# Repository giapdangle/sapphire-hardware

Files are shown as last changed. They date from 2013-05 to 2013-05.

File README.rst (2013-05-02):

Sapphire Hardware
=================

This repository contains the hardware designs for the Sapphire wireless platform.

License Information
-------------------

The contents of this repository are released under the Creative Commons Attribution-ShareAlike 3.0 Unported license.

See http://creativecommons.org/licenses/by-sa/3.0/ for more information.

Commercial Usage
----------------

While the license grants rights for commercial usage of the hardware designs, the Sapphire name, logo, and branding are NOT included in these rights.  If you intend to sell a derivative version of the hardware designs contained herein, you MUST remove the Sapphire name, logo, and any other markings that could confuse your product with one produced by Sapphire Open Systems.

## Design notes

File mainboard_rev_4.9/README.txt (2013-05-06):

Blue Sapphire
Schematic notes

CP2104 USB power:
The CP2104 is powered by VUSB, 5 volts direct from the USB connector (J2). VUSB flows through D1 to energize V_IN and the main regulator, unless a supply of higher voltage is applied to the DC input (J1). VUSB is fused at 500 mA in case a short circuit is connected to the DC input. The CP2104 itself is powered from VUSB and it's internal 3.4 volt regulator. 

The IO supply is directly connected to the CP2104 internal 3.4 volt supply. This is within the tolerance range of the 3.3 volt IO on the AVR microcontroller, however, it does mean that this board cannot be used with a main regulator (U2) at less than 3.3 volts. The advantage to this configuration is that the CP2104 is only (and entirely) powered by VUSB.  If there is no USB connection, the CP2104 will draw no current whatsoever. If the CP2104 VIO pin is connected to the main 3.3 volt board supply, it will leak several hundred microamps, even with the rest of the CP2104 unpowered.

CP2104 notes:
The EEPROM config for Vendor ID, S/N, etc can only be programmed once. This is a stark contrast to the FTDI parts. Note that C14 is required for EEPROM programming.

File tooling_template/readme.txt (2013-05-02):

Board name
Date

Board size:
X x Y in

Soldermask: Blue
Silkscreen: White
Plating: Silver

Gerbers:
main_c01.gbr	Top copper
main_c02.gbr	Bottom copper
main_sm1.gbr	Top solder mask
main_sm2.gbr	Bottom solder mask
main_sp1.gbr	Top solder paste
main_ss1.gbr	Top silk screen
main_ss2.gbr	Bottom silk screen

NC Drill:
main.drd

Do not populate:
x,x,x

Notes:

Contact:

Name
Company Name

E-mail

Phone

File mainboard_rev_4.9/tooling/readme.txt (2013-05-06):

Board name
Blue Sapphire 4.9

Board size:
1.45 x 2.61 in

Soldermask: Blue
Silkscreen: White
Plating: HASL

Gerbers:
main_c01.gbr	Top copper
main_c02.gbr	Bottom copper
main_sm1.gbr	Top solder mask
main_sm2.gbr	Bottom solder mask
main_sp1.gbr	Top solder paste
main_ss1.gbr	Top silk screen
main_ss2.gbr	Bottom silk screen

NC Drill:
main.drd

Do not populate:
R5

Contact:

Jeremy Billheimer
Sapphire Open Systems, LLC

jeremy@sapphireos.com

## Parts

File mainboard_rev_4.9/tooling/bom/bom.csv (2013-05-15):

Line item | Digikey PN | Description | Qty per unit | Ref Des | Notes
1 | 311-10KGRCT-ND | Res, 10K, 0603 | 2 | R3, R4
2 | 311-100KGRCT-ND | Res, 100K, 0603 | 1 | R2
3 | 311-150GRCT-ND | Res, 150, 0603 | 3 | R6, R7, R8
4 | 490-3895-1-ND | Cap, 1u, 0603 | 11 | C2, C3, C5, C6, C8, C10, C11, C12, C13, C15, C17
5 | 445-6797-1-ND | Cap, 22u, 0805 | 1 | C1
6 | 311-1371-1-ND | Cap, 4.7u 0805 | 1 | C14
7 | 445-5046-1-ND | Cap, 9p, 0603 | 4 | C7, C9, C18, C19
8 | 712-1332-1-ND | Cap, RF, 22p, 0603 | 1 | C16
9 | CG0603MLC-05ECT-ND | ESD, 0603 | 3 | D6, D7, D8
10 | 507-1519-1-ND | Fuse, 0805 | 1 | F1
11 | SER3628CT-ND | Crystal, 16MHz, SMT | 1 | Y1
12 | 887-1505-1-ND | Crystal, 32KHz, SMT | 1 | Y2
13 | BAS40-04-FDICT-ND | Diode, dual series, SOT23 | 2 | D1, D2
14 | 475-1410-1-ND | LED, green, 0805 | 1 | D3
15 | 754-1135-1-ND | LED, yellow, 0805 | 1 | D4
16 | 475-1415-1-ND | LED, red, 0805 | 1 | D5
17 | ATMEGA128RFA1-ZU-ND | IC, ATMega128RFA1, QFN64 | 1 | U3
18 | SST25VF080B-80-4I-S2AE-ND | IC, SPI Flash, 8 MBit, SOIC8 | 1 | U6
19 | 712-1538-1-ND | IC, Balun, 2450 MHz, DFN6 | 1 | U5
20 | MCP1703T-3302E/CBCT-ND | IC, LDO Reg, 3.3v, SOT23 | 1 | U2
21 | 336-2008-5-ND | IC, CP2104 USB, QFN24 | 1 | U4
22 | MCP121T-195I/LBCT-ND | IC, MCP121 Reset supervisor, SOT23 | 1 | U1
23 | CP-102A-ND | Conn, DC Power, PTH | 1 | J1
24 | H11671CT-ND | Conn, Mini USB, SMT | 1 | J2 | H11671TR-ND for 1500+, tape and reel
25 | S7014-ND | Conn, Female header, 1x16, PTH | 2 | J3, J4
26 | 450-1757-1-ND | Switch, tactile, SMT, SPST-NO | 1 | S1 | 450-1757-2-ND for 1200+, tape and reel
27 | 311-1.0MGRCT-ND | Res, 1M, 0603 | 1 | R1

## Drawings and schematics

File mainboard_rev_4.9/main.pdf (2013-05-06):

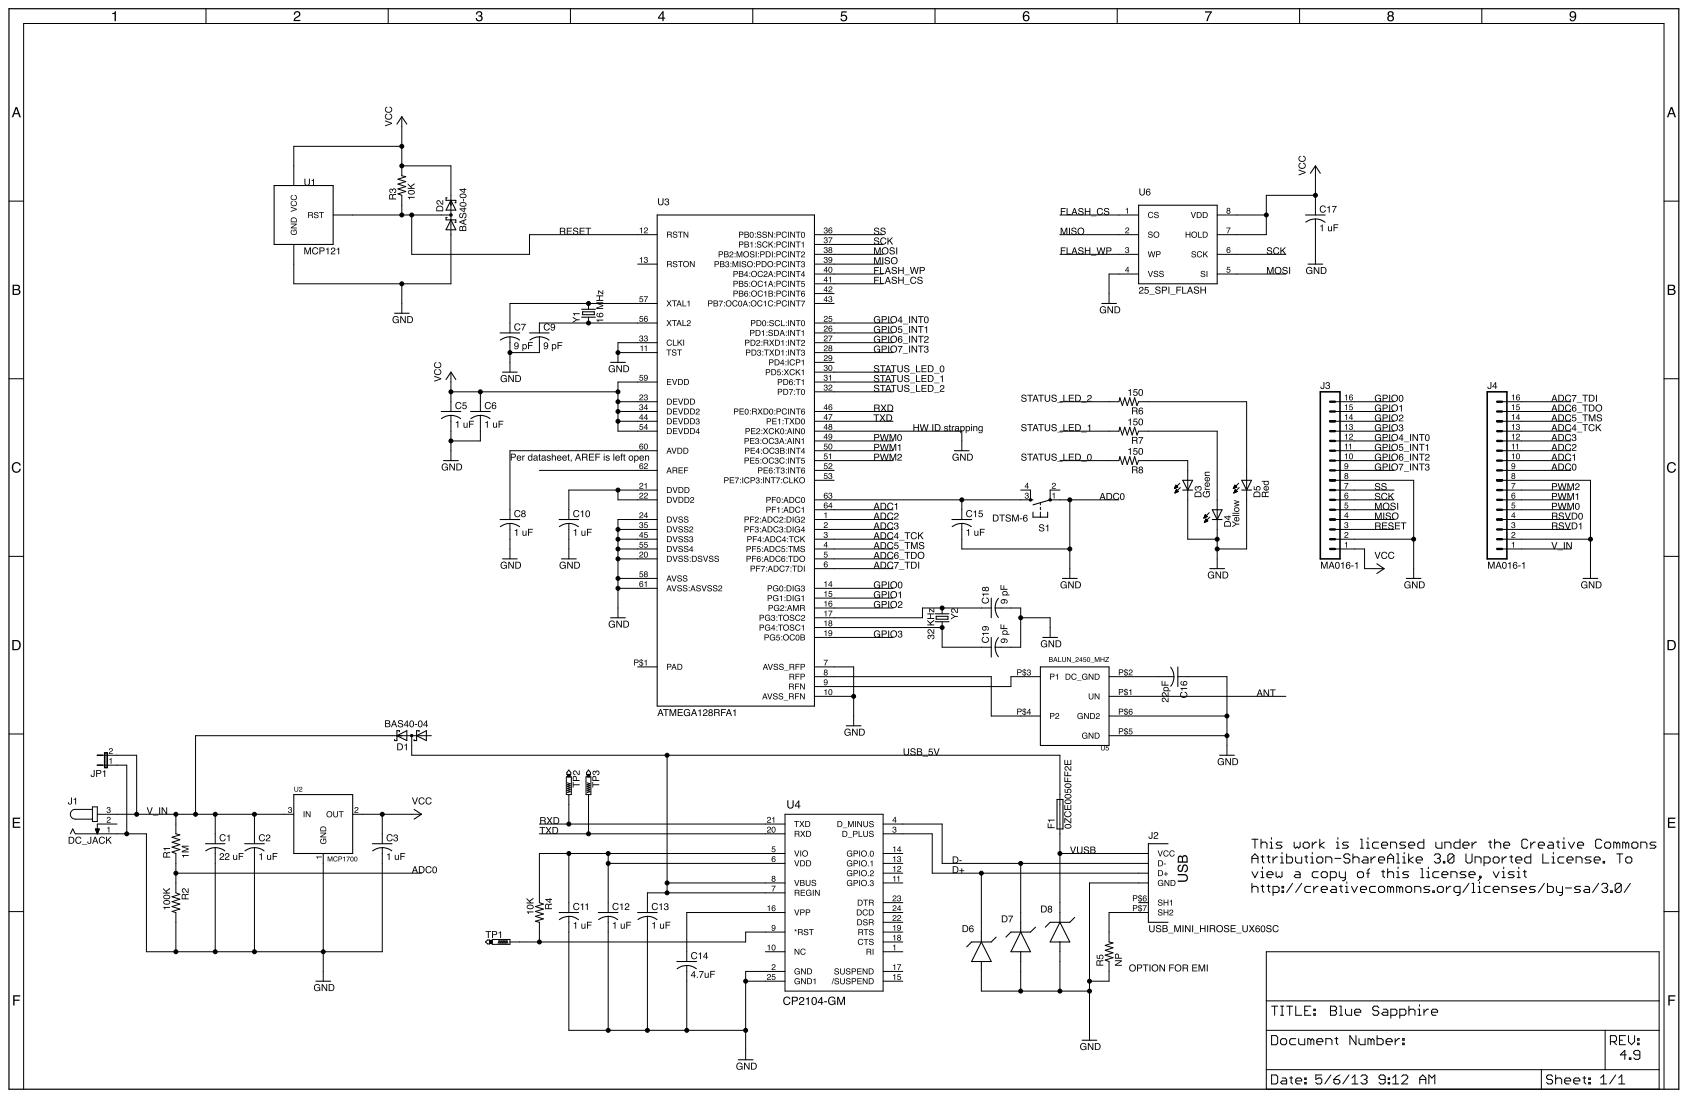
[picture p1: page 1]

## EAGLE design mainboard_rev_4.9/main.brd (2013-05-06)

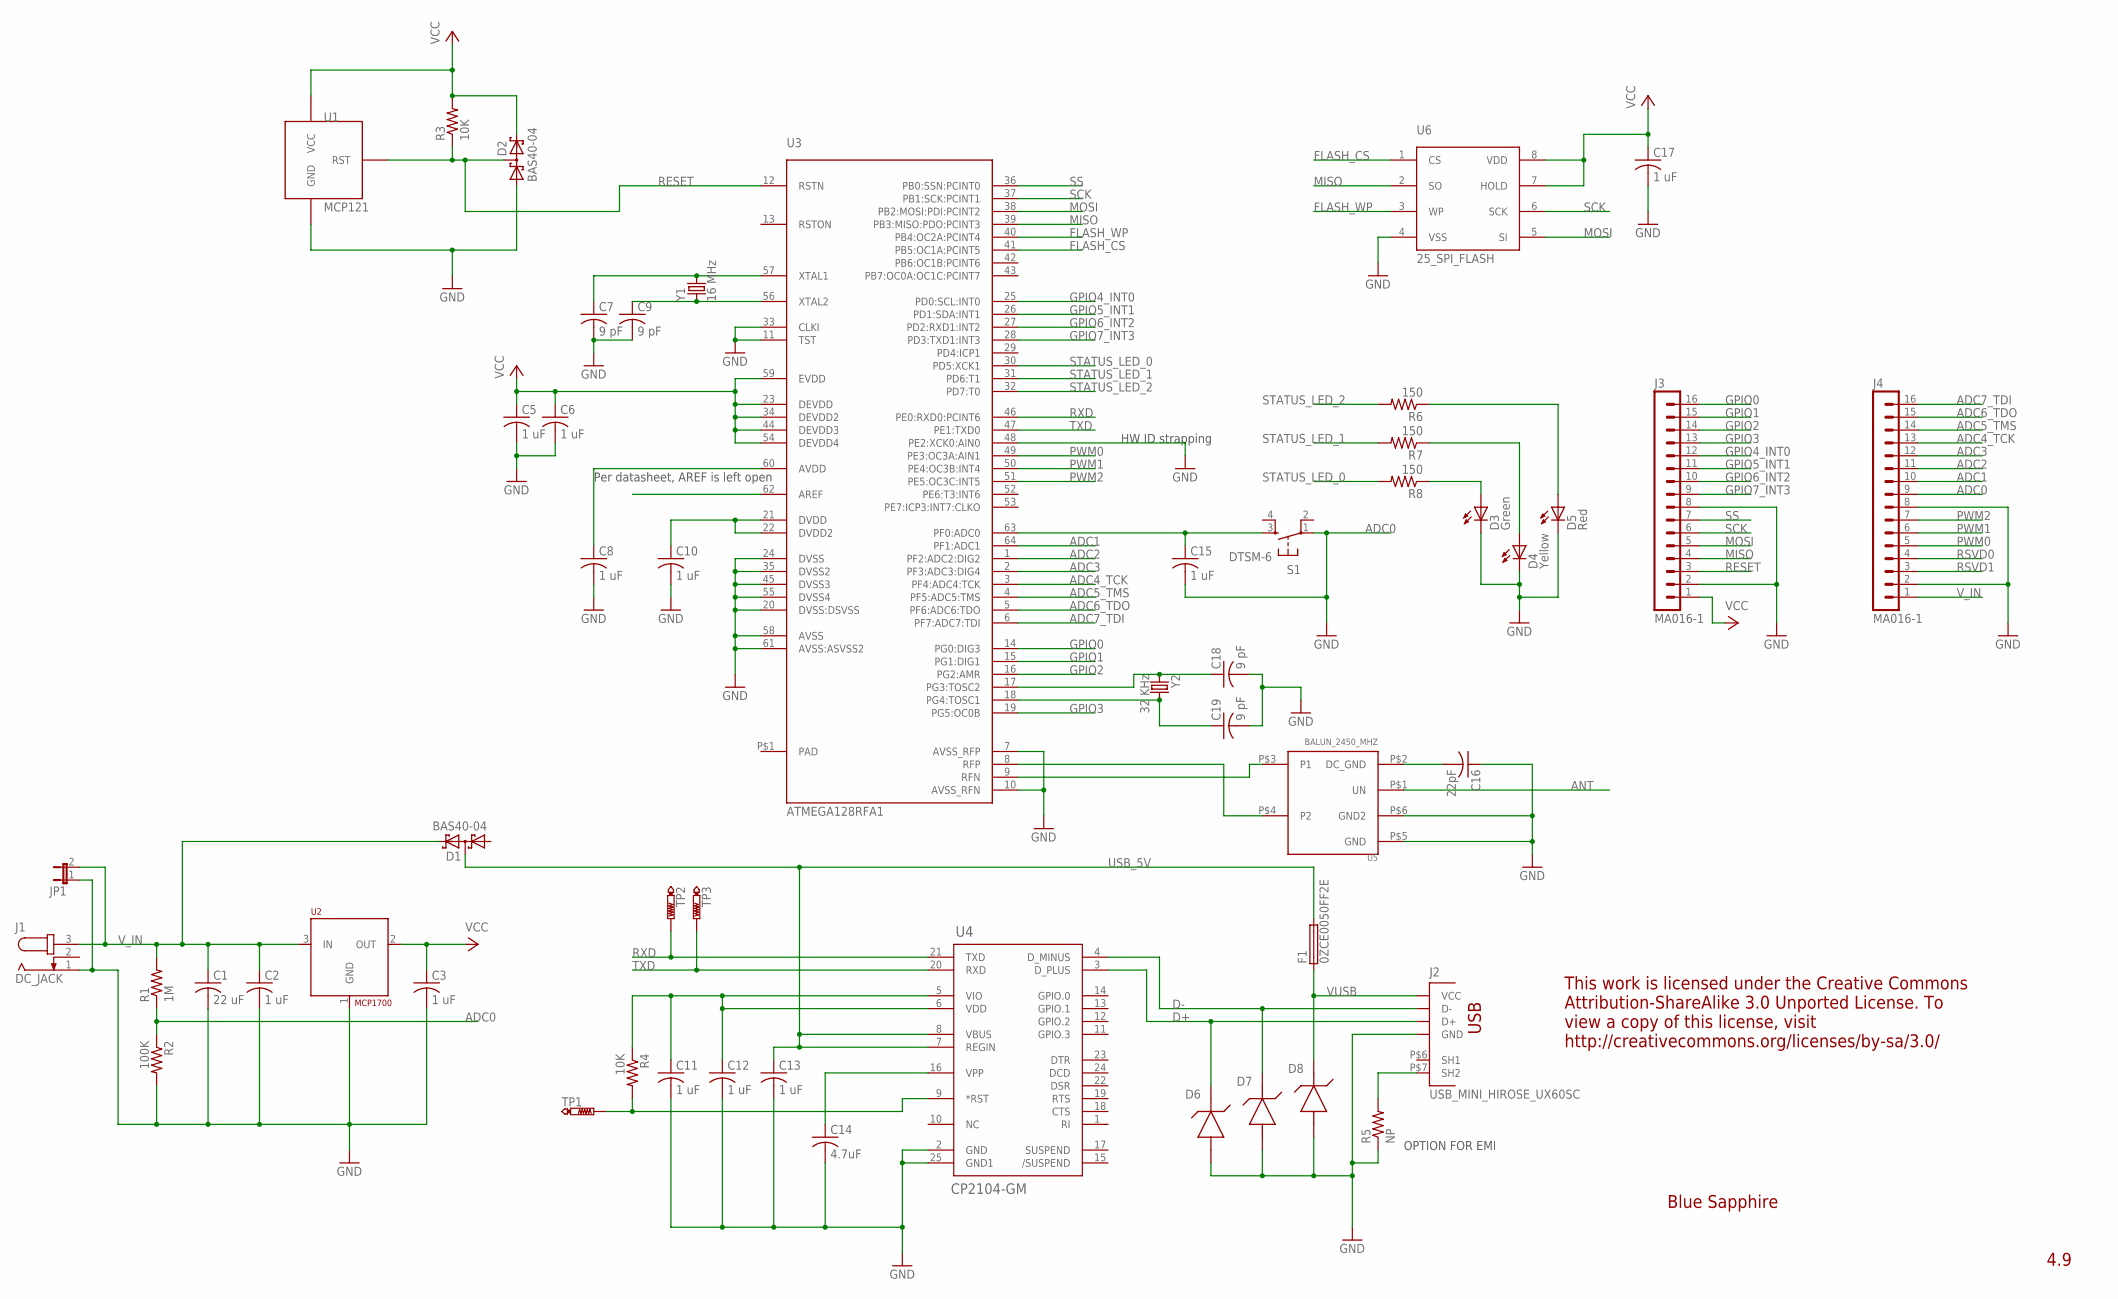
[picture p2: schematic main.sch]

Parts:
C1: 22 uF; C0805K
C2, C3, C5, C6, C8, C10, C11, C12, C13, C15, C17: 1 uF; C0603K
C7, C9, C18, C19: 9 pF; C0603K
C14: 4.7uF; C0805K
C16: 22pF; C0603K
D1, D2: BAS40-04; SOT23
D3: Green; CHIPLED_0805
D4: Yellow; CHIPLED_0805
D5: Red; CHIPLED_0805
D6, D7, D8: CG0603MLC; C0603
F1: 0ZCE0050FF2E; C0805
J1: DC_JACK; CONN_DC_JACK
J2: USB_MINI_HIROSE_UX60SC; USB-MINI-B_HIROSE_UX60SC
J3, J4: MA016-1
JP1: JP1E; JP1
R1: 1M; R0603
R2: 100K; R0603
R3, R4: 10K; R0603
R5: NP; R0603
R6, R7, R8: 150; R0603
S1: DTSM-6
TP1, TP2, TP3: PTR1B1,27; B1,27
U1: MCP121; SOT23
U2: MCP1700; SOT23
U3: ATMEGA128RFA1; MLF64
U4: CP2104-GM; QFN24_4X4
U5: BALUN_2450_MHZ; BALUN_0805
U6: 25_SPI_FLASH; SO-8WIDE
Y1: 16 MHz; XTAL_3.2X2.5
Y2: 32 KHz; XTAL_3.2X1.5

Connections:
ADC0: C15.1, J4.9, R1.1, R2.1, S1.3, U3.63 (PF0:ADC0)
ADC1: J4.10, U3.64 (PF1:ADC1)
ADC2: J4.11, U3.1 (PF2:ADC2:DIG2)
ADC3: J4.12, U3.2 (PF3:ADC3:DIG4)
ADC4_TCK: J4.13, U3.3 (PF4:ADC4:TCK)
ADC5_TMS: J4.14, U3.4 (PF5:ADC5:TMS)
ADC6_TDO: J4.15, U3.5 (PF6:ADC6:TDO)
ADC7_TDI: J4.16, U3.6 (PF7:ADC7:TDI)
ANT: U5.P$1 (UN)
AREF: U3.62 (AREF)
AVDD: C8.1, U3.60 (AVDD)
D+: D6.2 (LINE), J2.P$3 (D+), U4.3 (D_PLUS)
D-: D7.2 (LINE), J2.P$2 (D-), U4.4 (D_MINUS)
DVDD: C10.1, U3.21 (DVDD), U3.22 (DVDD2)
FLASH_CS: U3.41 (PB5:OC1A:PCINT5), U6.1 (CS)
FLASH_WP: U3.40 (PB4:OC2A:PCINT4), U6.3 (WP)
GND: C1.2, C2.2, C3.2, C5.2, C6.2, C7.2, C8.2, C9.2, C10.2, C11.2, C12.2, C13.2, C14.2, C15.2, C16.1, C17.2, C18.2, C19.2, D2.1 (A1), D3.C, D4.C, D5.C, D6.1 (GND), D7.1 (GND), D8.1 (GND), J1.1, J2.P$5 (GND), J3.2, J3.8, J4.2, J4.8, JP1.1, R2.2, R5.1, S1.1, U1.3 (GND), U2.1 (GND), U3.7 (AVSS_RFP), U3.10 (AVSS_RFN), U3.11 (TST), U3.20 (DVSS:DSVSS), U3.24 (DVSS), U3.33 (CLKI), U3.35 (DVSS2), U3.45 (DVSS3), U3.48 (PE2:XCK0:AIN0), U3.55 (DVSS4), U3.58 (AVSS), U3.61 (AVSS:ASVSS2), U4.2 (GND), U4.25 (GND1), U5.P$5 (GND), U5.P$6 (GND2), U6.4 (VSS)
GPIO0: J3.16, U3.14 (PG0:DIG3)
GPIO1: J3.15, U3.15 (PG1:DIG1)
GPIO2: J3.14, U3.16 (PG2:AMR)
GPIO3: J3.13, U3.19 (PG5:OC0B)
GPIO4_INT0: J3.12, U3.25 (PD0:SCL:INT0)
GPIO5_INT1: J3.11, U3.26 (PD1:SDA:INT1)
GPIO6_INT2: J3.10, U3.27 (PD2:RXD1:INT2)
GPIO7_INT3: J3.9, U3.28 (PD3:TXD1:INT3)
MISO: J3.4, U3.39 (PB3:MISO:PDO:PCINT3), U6.2 (SO)
MOSI: J3.5, U3.38 (PB2:MOSI:PDI:PCINT2), U6.5 (SI)
unnamed: C16.2, U5.P$2 (DC_GND)
unnamed: C19.1, U3.18 (PG4:TOSC1), Y2.P$2 (2)
unnamed: U3.8 (RFP), U5.P$4 (P2)
unnamed: R4.2, TP1.TP, U4.9 (*RST)
unnamed: D3.A, R8.1
unnamed: J2.P$7 (SH2), R5.2
unnamed: D4.A, R7.1
unnamed: D5.A, R6.1
unnamed: U3.9 (RFN), U5.P$3 (P1)
unnamed: C18.1, U3.17 (PG3:TOSC2), Y2.P$1 (1)
unnamed: C14.1, U4.16 (VPP)
PWM0: J4.5, U3.49 (PE3:OC3A:AIN1)
PWM1: J4.6, U3.50 (PE4:OC3B:INT4)
PWM2: J4.7, U3.51 (PE5:OC3C:INT5)
RESET: D2.3 (C1A2), J3.3, R3.1, U1.1 (RST), U3.12 (RSTN)
RSVD0: J4.4
RSVD1: J4.3
RXD: TP2.TP, U3.46 (PE0:RXD0:PCINT6), U4.21 (TXD)
SCK: J3.6, U3.37 (PB1:SCK:PCINT1), U6.6 (SCK)
SS: J3.7, U3.36 (PB0:SSN:PCINT0)
STATUS_LED_0: R8.2, U3.30 (PD5:XCK1)
STATUS_LED_1: R7.2, U3.31 (PD6:T1)
STATUS_LED_2: R6.2, U3.32 (PD7:T0)
TXD: TP3.TP, U3.47 (PE1:TXD0), U4.20 (RXD)
USB_5V: C13.1, D1.3 (C1A2), F1.2, U4.7 (REGIN), U4.8 (VBUS)
USB_VDD: C11.1, C12.1, R4.1, U4.5 (VIO), U4.6 (VDD)
VCC: C3.1, C5.1, C6.1, C17.1, D2.2 (C2), J3.1, R3.2, U1.2 (VCC), U2.2 (OUT), U3.23 (DEVDD), U3.34 (DEVDD2), U3.44 (DEVDD3), U3.54 (DEVDD4), U3.59 (EVDD), U6.7 (HOLD), U6.8 (VDD)
VUSB: D8.2 (LINE), F1.1, J2.P$1 (VCC)
V_IN: C1.1, C2.1, D1.2 (C2), J1.3, J4.1, JP1.2, R1.2, U2.3 (IN)
XTAL1: C7.1, U3.57 (XTAL1), Y1.P$3 (2)
XTAL2: C9.1, U3.56 (XTAL2), Y1.P$1 (1)

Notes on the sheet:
Per datasheet, AREF is left open
HW ID strapping
OPTION FOR EMI
Blue Sapphire
4.9
This work is licensed under the Creative Commons Attribution-ShareAlike 3.0 Unported License. To view a copy of this license, visit http://creativecommons.org/licenses/by-sa/3.0/

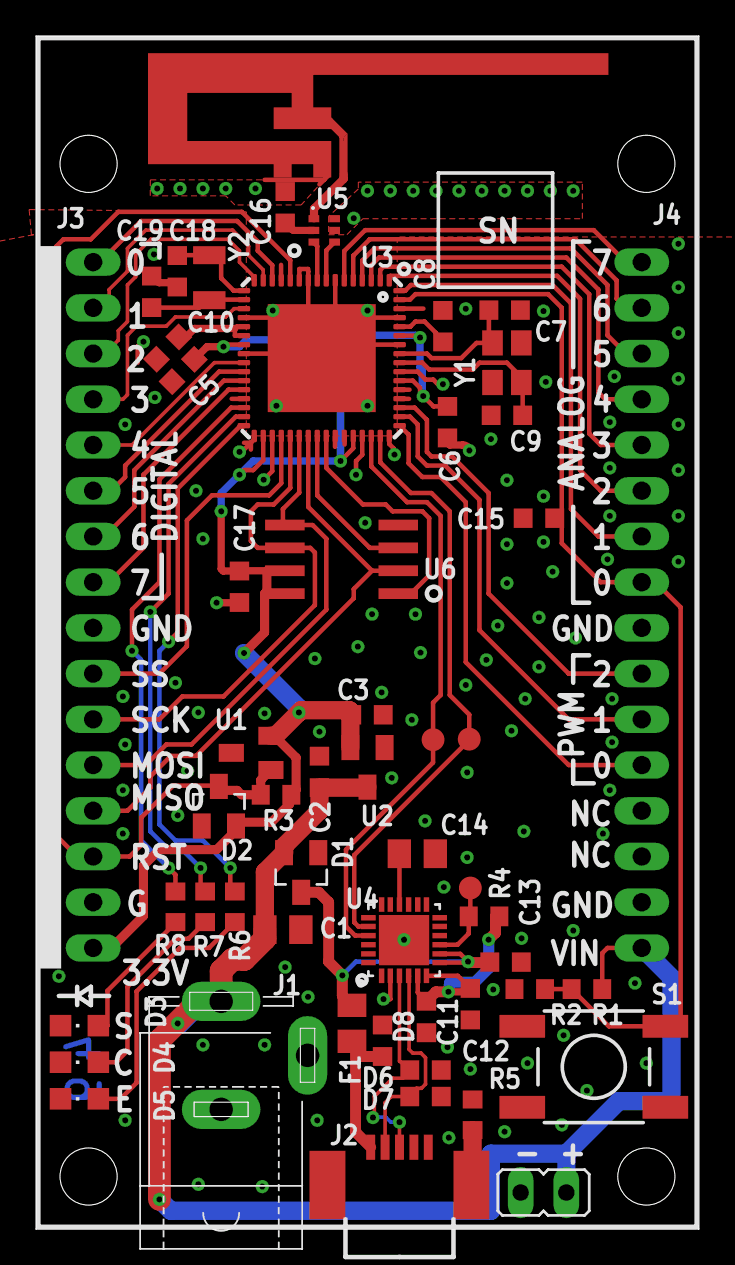
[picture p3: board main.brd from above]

Board: 2 copper layers, 36.8 x 66.3 mm, 53 parts (0 on the bottom side), 54 nets.

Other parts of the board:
ANT: F_ANTENNA_2_4GHZ

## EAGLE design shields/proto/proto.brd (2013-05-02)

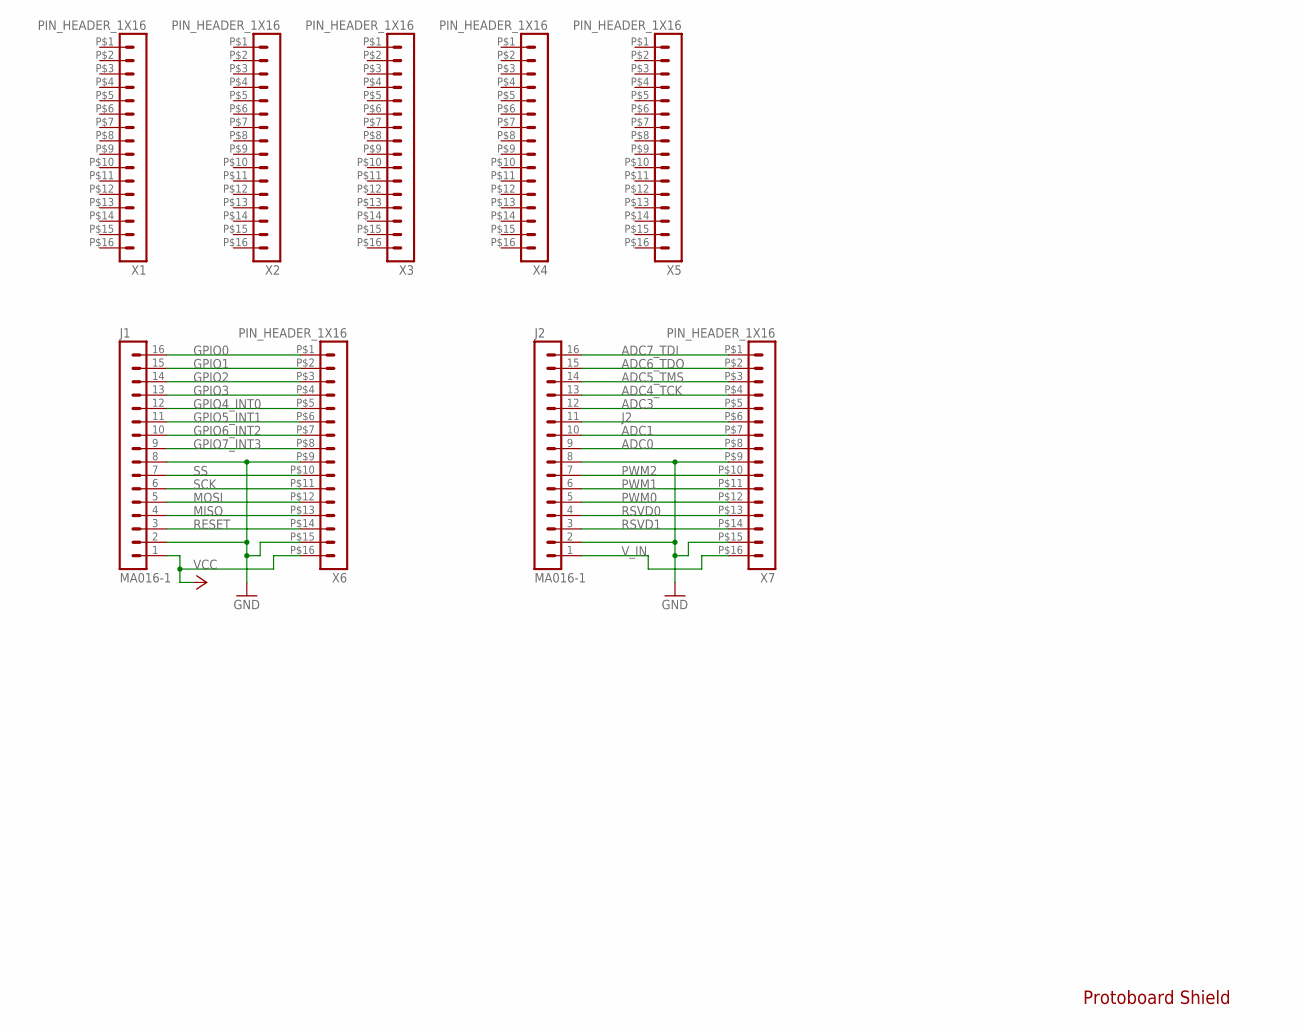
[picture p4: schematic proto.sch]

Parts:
J1, J2: MA016-1
X1, X2, X3, X4, X5, X6, X7: PIN_HEADER_1X16

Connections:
ADC0: J2.9, X7.P$8 (8)
ADC1: J2.10, X7.P$7 (7)
ADC3: J2.12, X7.P$5 (5)
ADC4_TCK: J2.13, X7.P$4 (4)
ADC5_TMS: J2.14, X7.P$3 (3)
ADC6_TDO: J2.15, X7.P$2 (2)
ADC7_TDI: J2.16, X7.P$1 (1)
GND: J1.2, J1.8, J2.2, J2.8, X6.P$9 (9), X6.P$15 (15), X7.P$9 (9), X7.P$15 (15)
GPIO0: J1.16, X6.P$1 (1)
GPIO1: J1.15, X6.P$2 (2)
GPIO2: J1.14, X6.P$3 (3)
GPIO3: J1.13, X6.P$4 (4)
GPIO4_INT0: J1.12, X6.P$5 (5)
GPIO5_INT1: J1.11, X6.P$6 (6)
GPIO6_INT2: J1.10, X6.P$7 (7)
GPIO7_INT3: J1.9, X6.P$8 (8)
J2: J2.11, X7.P$6 (6)
MISO: J1.4, X6.P$13 (13)
MOSI: J1.5, X6.P$12 (12)
PWM0: J2.5, X7.P$12 (12)
PWM1: J2.6, X7.P$11 (11)
PWM2: J2.7, X7.P$10 (10)
RESET: J1.3, X6.P$14 (14)
RSVD0: J2.4, X7.P$13 (13)
RSVD1: J2.3, X7.P$14 (14)
SCK: J1.6, X6.P$11 (11)
SS: J1.7, X6.P$10 (10)
VCC: J1.1, X6.P$16 (16)
V_IN: J2.1, X7.P$16 (16)

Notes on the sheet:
Protoboard Shield

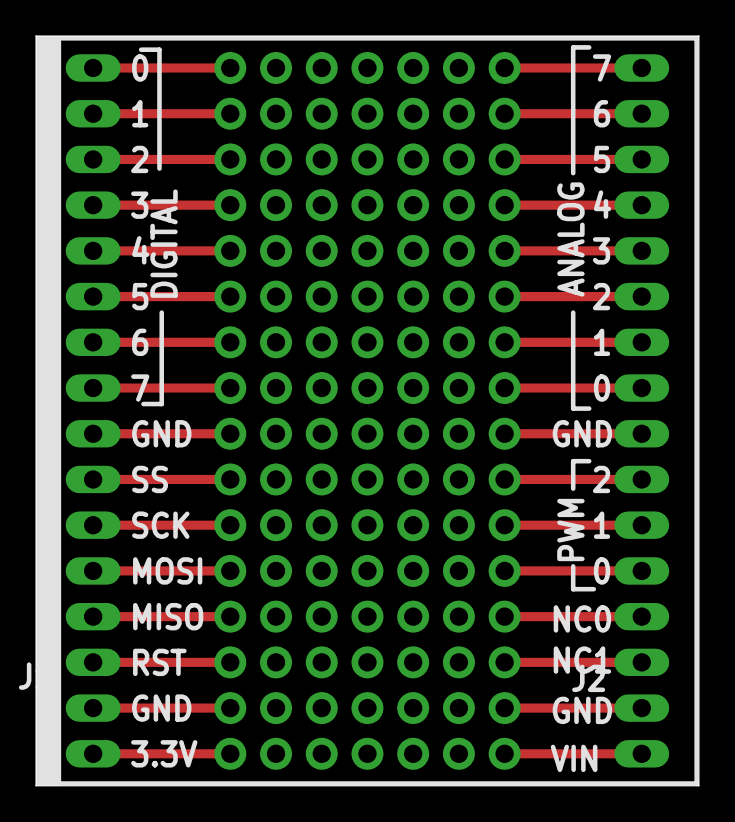
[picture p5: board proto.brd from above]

Board: 2 copper layers, 36.8 x 41.7 mm, 9 parts (0 on the bottom side), 29 nets.

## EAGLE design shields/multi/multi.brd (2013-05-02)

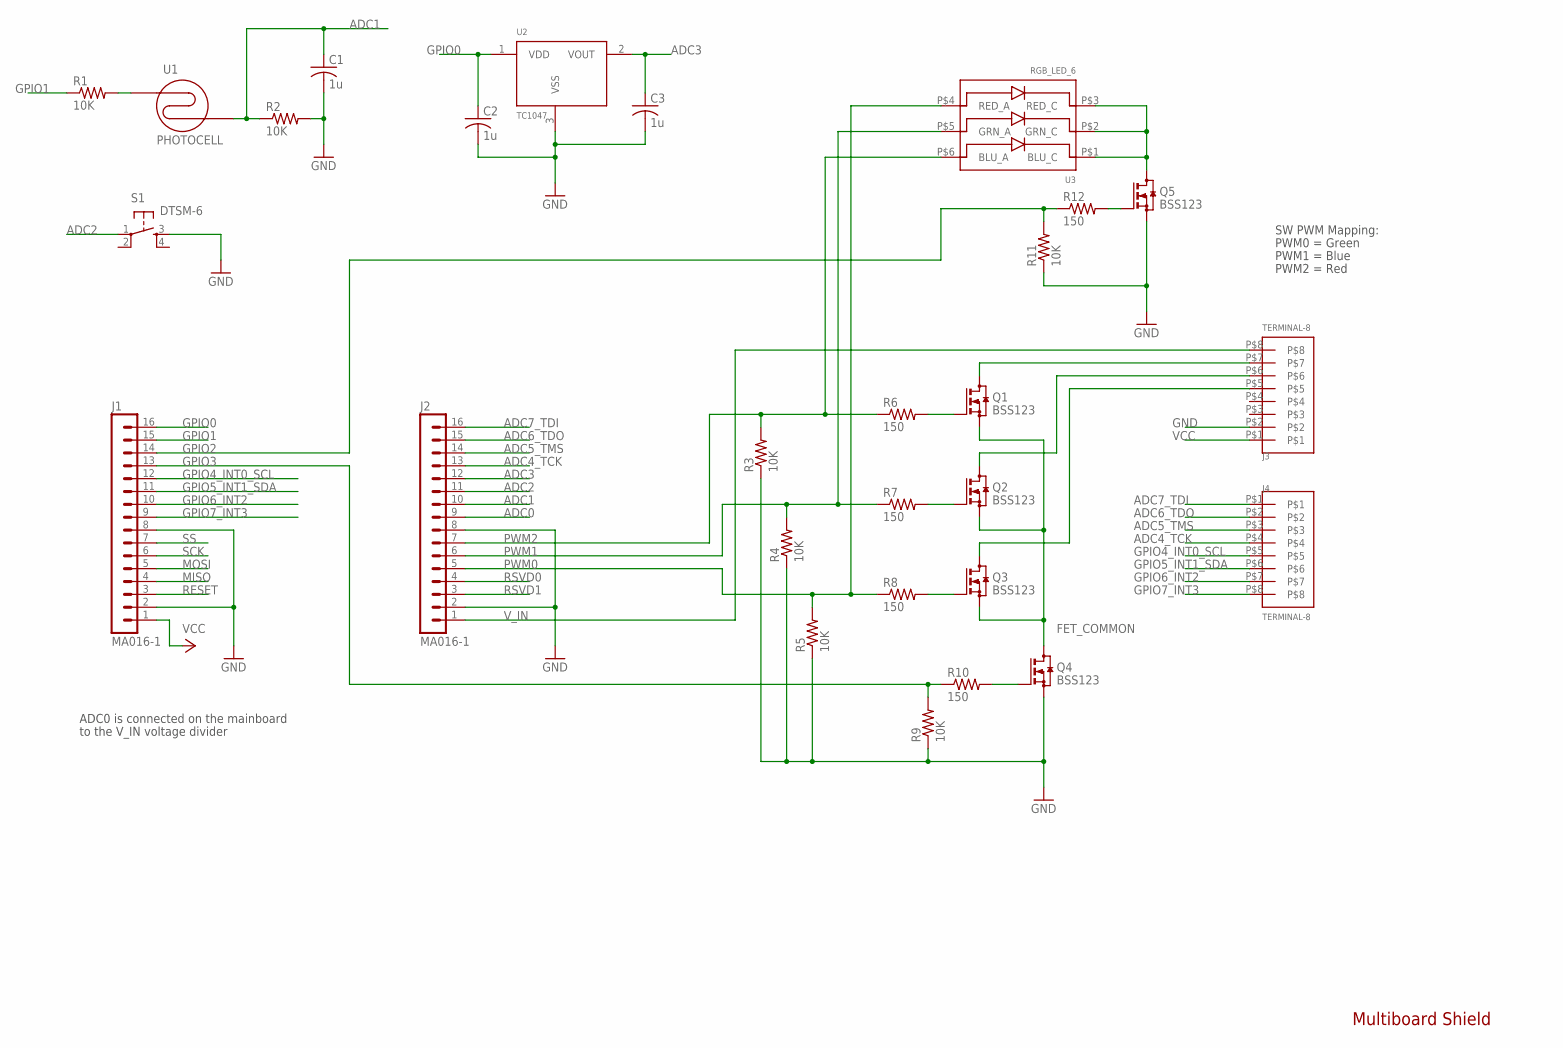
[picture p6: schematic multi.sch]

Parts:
C1, C2, C3: 1u; C0603K
J1, J2: MA016-1
J3, J4: TERMINAL-8
Q1, Q2, Q3, Q4, Q5: BSS123; SOT23
R1, R2, R3, R4, R5, R9, R11: 10K; R0603
R6, R7, R8, R10, R12: 150; R0603
S1: DTSM-6
U1: PHOTOCELL
U2: TC1047; SOT23
U3: RGB_LED_6; PLCC6

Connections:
ADC0: J2.9
ADC1: C1.1, J2.10, R2.1, U1.P$2
ADC2: J2.11, S1.1
ADC3: C3.1, J2.12, U2.2 (VOUT)
ADC4_TCK: J2.13, J4.P$4
ADC5_TMS: J2.14, J4.P$3
ADC6_TDO: J2.15, J4.P$2
ADC7_TDI: J2.16, J4.P$1
FET_COMMON: Q1.2 (S), Q2.2 (S), Q3.2 (S), Q4.3 (D)
GND: C1.2, C2.2, C3.2, J1.2, J1.8, J2.2, J2.8, J3.P$2, Q4.2 (S), Q5.2 (S), R2.2, R3.1, R4.1, R5.1, R9.1, R11.1, S1.3, U2.3 (VSS)
GPIO0: C2.1, J1.16, U2.1 (VDD)
GPIO1: J1.15, R1.1
GPIO2: J1.14, R11.2, R12.1
GPIO3: J1.13, R9.2, R10.1
GPIO4_INT0_SCL: J1.12, J4.P$5
GPIO5_INT1_SDA: J1.11, J4.P$6
GPIO6_INT2: J1.10, J4.P$7
GPIO7_INT3: J1.9, J4.P$8
INA: Q2.1 (G), R7.2
INB: Q1.1 (G), R6.2
MISO: J1.4
MOSI: J1.5
unnamed: R1.2, U1.P$1
unnamed: Q5.3 (D), U3.P$1 (BLU_C), U3.P$2 (GRN_C), U3.P$3 (RED_C)
unnamed: Q5.1 (G), R12.2
unnamed: Q3.1 (G), R8.2
unnamed: Q4.1 (G), R10.2
OUT0: J3.P$5, Q3.3 (D)
OUT1: J3.P$6, Q2.3 (D)
OUT2: J3.P$7, Q1.3 (D)
PWM0: J2.5, R5.2, R8.1, U3.P$4 (RED_A)
PWM1: J2.6, R4.2, R7.1, U3.P$5 (GRN_A)
PWM2: J2.7, R3.2, R6.1, U3.P$6 (BLU_A)
RESET: J1.3
RSVD0: J2.4
RSVD1: J2.3
SCK: J1.6
SS: J1.7
VCC: J1.1, J3.P$1
V_IN: J2.1, J3.P$8

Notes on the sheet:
SW PWM Mapping:
PWM0 = Green
PWM1 = Blue
PWM2 = Red
ADC0 is connected on the mainboard
to the V_IN voltage divider
Multiboard Shield

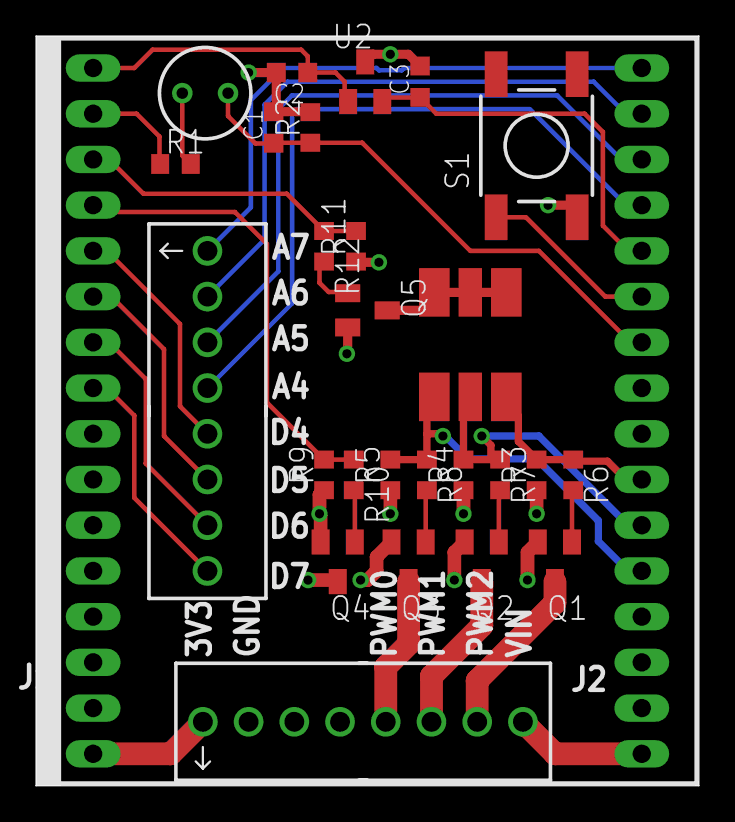
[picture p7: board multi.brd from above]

Board: 2 copper layers, 36.8 x 41.7 mm, 28 parts (0 on the bottom side), 32 nets.

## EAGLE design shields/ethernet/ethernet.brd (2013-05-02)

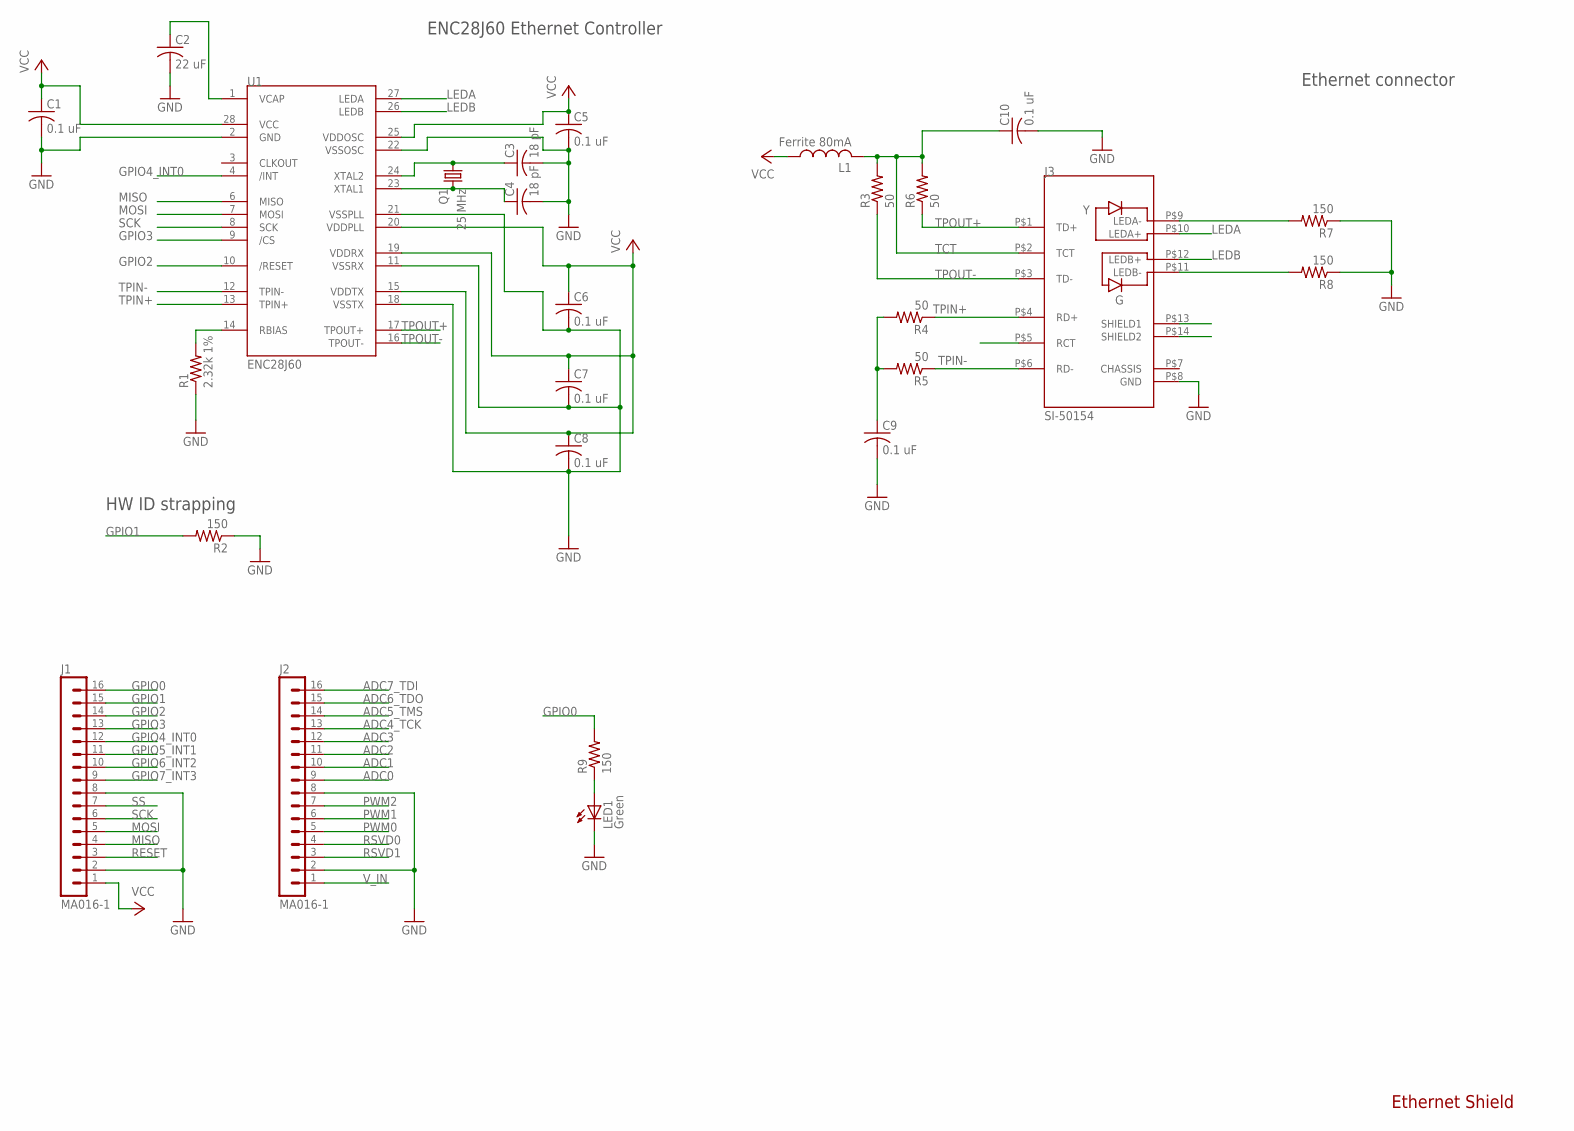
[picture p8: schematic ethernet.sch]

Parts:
C1, C5, C6, C7, C8, C9, C10: 0.1 uF; C0603K
C2: 22 uF; C0805K
C3, C4: 18 pF; C0603K
J1, J2: MA016-1
J3: SI-50154
L1: Ferrite 80mA; L2012C
LED1: Green; CHIPLED_0805
Q1: 25 MHz; CTS406
R1: 2.32k 1%; R0603
R2, R7, R8, R9: 150; R0603
R3, R4, R5, R6: 50; R0603
U1: ENC28J60; SO-28W

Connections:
ADC0: J2.9
ADC1: J2.10
ADC2: J2.11
ADC3: J2.12
ADC4_TCK: J2.13
ADC5_TMS: J2.14
ADC6_TDO: J2.15
ADC7_TDI: J2.16
GND: C1.2, C2.2, C3.2, C4.2, C5.2, C6.2, C7.2, C8.2, C9.2, C10.2, J1.2, J1.8, J2.2, J2.8, J3.P$8 (GND), LED1.C, R1.1, R2.1, R7.1, R8.1, U1.2 (GND), U1.11 (VSSRX), U1.18 (VSSTX), U1.21 (VSSPLL), U1.22 (VSSOSC)
GPIO0: J1.16, R9.2
GPIO1: J1.15, R2.2
GPIO2: J1.14, U1.10 (/RESET)
GPIO3: J1.13, U1.9 (/CS)
GPIO4_INT0: J1.12, U1.4 (/INT)
GPIO5_INT1: J1.11
GPIO6_INT2: J1.10
GPIO7_INT3: J1.9
LEDA: J3.P$10 (LEDA+), U1.27 (LEDA)
LEDA-: J3.P$9 (LEDA-), R7.2
LEDB: J3.P$12 (LEDB+), U1.26 (LEDB)
LEDB-: J3.P$11 (LEDB-), R8.2
MISO: J1.4, U1.6 (MISO)
MOSI: J1.5, U1.7 (MOSI)
unnamed: LED1.A, R9.1
PWM0: J2.5
PWM1: J2.6
PWM2: J2.7
RBIAS: R1.2, U1.14 (RBIAS)
RESET: J1.3
RSVD0: J2.4
RSVD1: J2.3
SCK: J1.6, U1.8 (SCK)
SS: J1.7
TCT: C10.1, J3.P$2 (TCT), L1.2, R3.2, R6.2
TPIN+: J3.P$4 (RD+), R4.1, U1.13 (TPIN+)
TPIN-: J3.P$6 (RD-), R5.1, U1.12 (TPIN-)
TPIN_CAP: C9.1, R4.2, R5.2
TPOUT+: J3.P$1 (TD+), R6.1, U1.17 (TPOUT+)
TPOUT-: J3.P$3 (TD-), R3.1, U1.16 (TPOUT-)
VCAP: C2.1, U1.1 (VCAP)
VCC: C1.1, C5.1, C6.1, C7.1, C8.1, J1.1, L1.1, U1.15 (VDDTX), U1.19 (VDDRX), U1.20 (VDDPLL), U1.25 (VDDOSC), U1.28 (VCC)
V_IN: J2.1
XTAL3: C3.1, Q1.1, U1.24 (XTAL2)
XTAL4: C4.1, Q1.3 (2), U1.23 (XTAL1)

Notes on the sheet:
ENC28J60 Ethernet Controller
Ethernet connector
HW ID strapping
Ethernet Shield

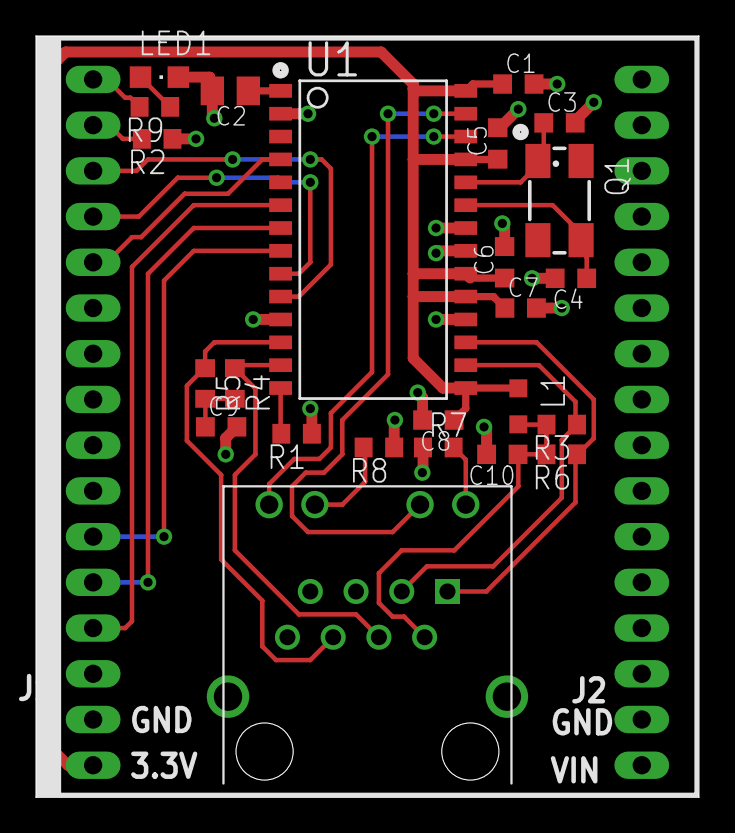
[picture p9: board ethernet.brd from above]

Board: 2 copper layers, 36.8 x 42.3 mm, 26 parts (0 on the bottom side), 25 nets.

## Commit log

2013-05-02 Public hardware release
    [ethernet.brd, ethernet.sch, main.brd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]
2013-05-02 Generated tooling data
    [bom.csv, centroid.csv, main.brd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]
2013-05-06 Added schematic notes and a few missing ref des to PCB
    [centroid.csv, main.brd, main.sch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]
2013-05-06 Added final tooling data
    [centroid.csv, main.brd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]
2013-05-06 Removed JP1 from centroid file and added schematic pdf
    [centroid.csv]
2013-05-15 Fixed typo in BOM
    [bom.csv]
